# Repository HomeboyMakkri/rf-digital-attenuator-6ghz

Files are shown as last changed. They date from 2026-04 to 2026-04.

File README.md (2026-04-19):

# rf-digital-attenuator-6ghz 📡






A student open-source hardware project featuring a **6-bit Digital RF Attenuator** capable
of operating up to 6 GHz. Controlled by an **STM32F407VET6** and based on the **HMC624A**
(Analog Devices) silicon, this device provides precise signal level control via a simple 
USB-UART CLI or direct SPI interface.
The RF signal path features a grounded coplanar waveguide (GCPW) structure to ensure 50 Ohm impedance matching across the entire operating frequency range.

### Project Context & Disclaimer ⚠️

This project is my first deep dive into the world of embedded systems and RF design. The control logic is implemented using STM32F4 (developed via CubeMX + Keil with HAL libraries), communicating with the HMC624A attenuator via SPI. Serial communication is handled by an FT232RL bridge at a baud rate of 115200.

The hardware was designed from scratch in Altium Designer. Please note: this project is a learning experience. While it is fully functional, it should not be treated as a definitive reference or a textbook example. I am eager to learn and would sincerely appreciate any constructive criticism or suggestions for improvement!

💡 Quick Tip: Check the Project Structure section at the bottom of this file for easy navigation through the firmware and hardware source files.

---
## Control Command to set the attunuation level
Connect via any Serial Terminal (115200 8N1):
* `ATTEN XX.X` — Set attenuation (0 to 31.5)

## 🚀 Features

* **Wide Frequency Range:** Stable performance from 100 MHz to 6.0 GHz.
* **High Precision:** 6-bit attenuation with a fine 0.5 dB step resolution.
* **Robust RF Design:** 50 Ohm matched Coplanar Waveguides (CPW) optimized for 1.6mm FR4.
* **Dual Control:** Command-line interface (CLI) via FT232 USB-UART or high-speed SPI.
* **Plug-and-Play:** Powered and controlled through a single USB Type-C connector.

---

## 📊 Technical Specifications

| Parameter | Value | Notes |
| :--- | :--- | :--- |
| **Frequency Range** | 0.1 — 6.0 GHz | Optimized for 6 GHz |
| **Attenuation Range** | 0 — 31.5 dB | 6-bit control |
| **Step Size** | 0.5 dB | ±0.15 dB Typical Accuracy |
| **Insertion Loss** | ~2.2 dB | @ 2.0 GHz |
| **Input P1dB** | +24 dBm | 1dB Compression Point |
| **Control Interface** | UART (USB) / SPI | 115200 Baud |
| **Input Voltage** | 5.0 V | Via USB Type-C |

---

## 📸 Hardware Gallery

### PCB Overview
| Top View (MCU Side) | Bottom View (RF Side) |
| :---: | :---: |
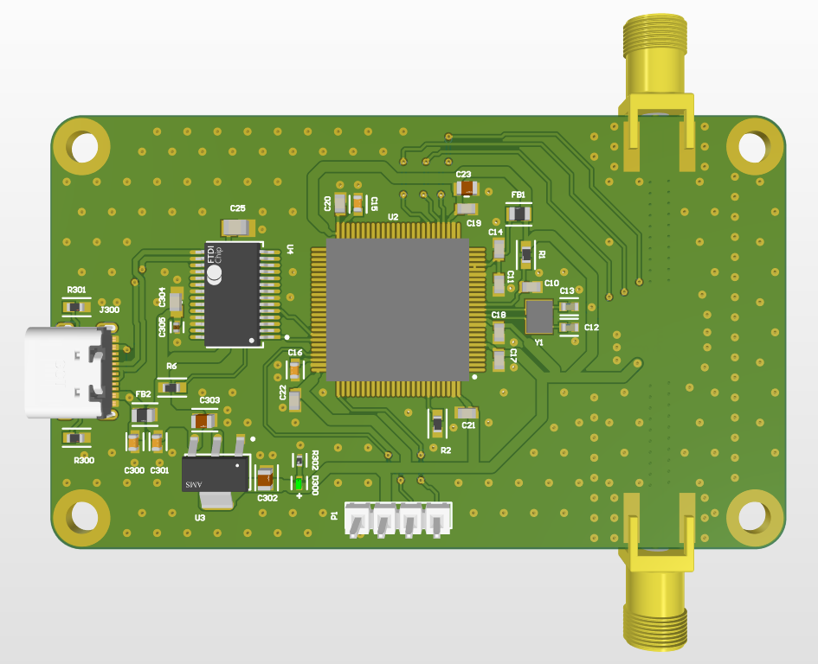
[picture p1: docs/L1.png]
L1
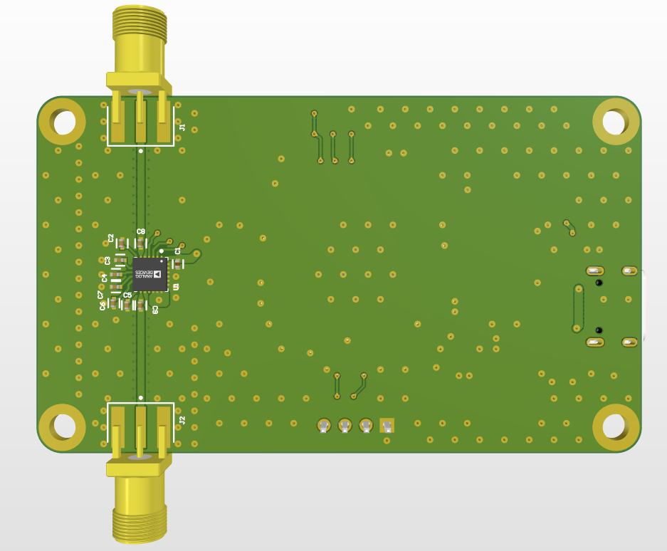
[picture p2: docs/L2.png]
L2
|  |  |

### Key Components
| STM32F407VET6 | HMC624A Attenuator | FT232 UART Bridge |
| :---: | :---: | :---: |
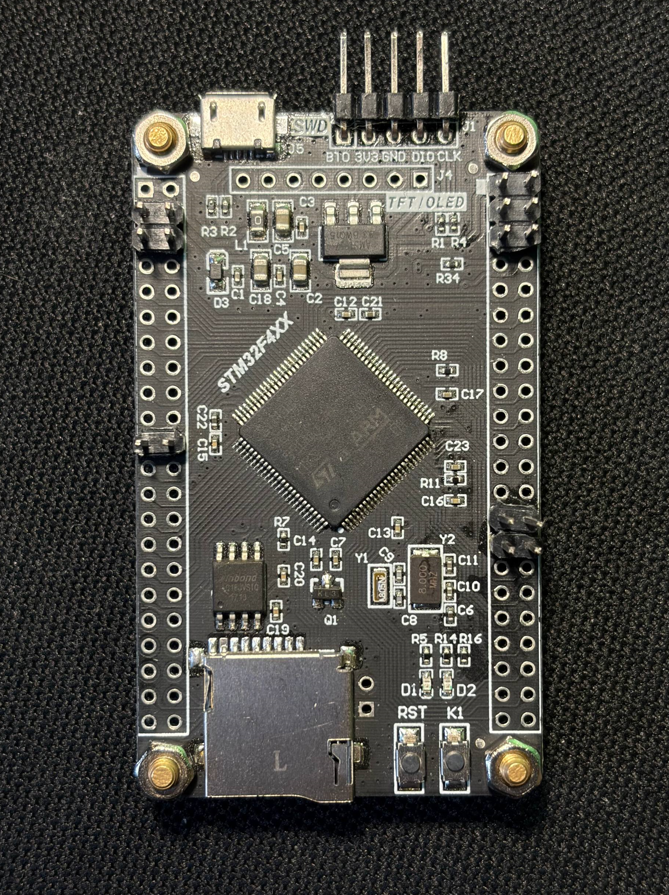
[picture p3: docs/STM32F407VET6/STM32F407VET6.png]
MCU
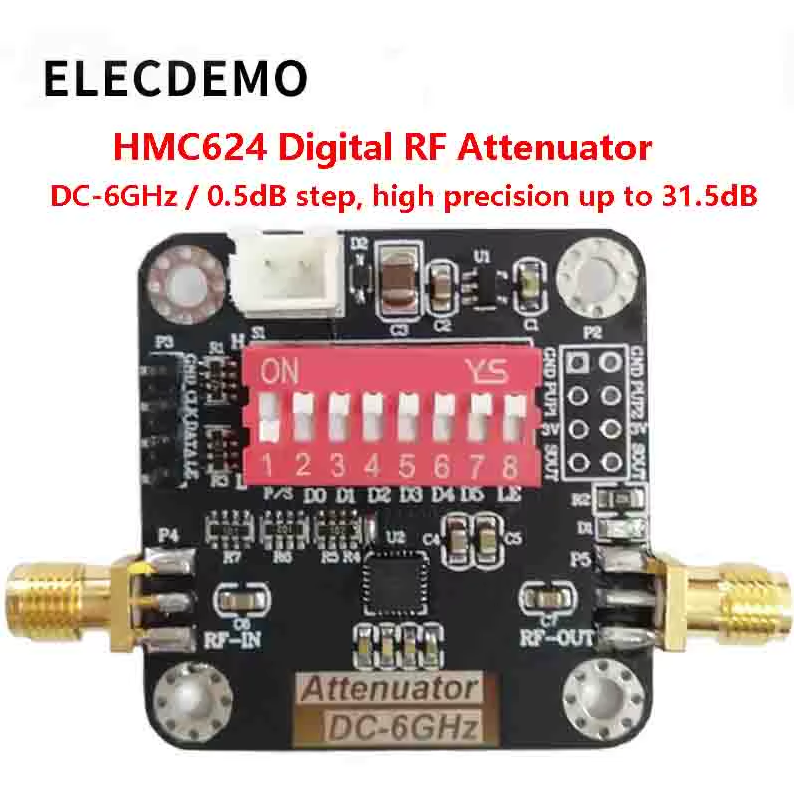
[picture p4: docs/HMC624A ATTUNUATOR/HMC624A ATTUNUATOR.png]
HMC624A
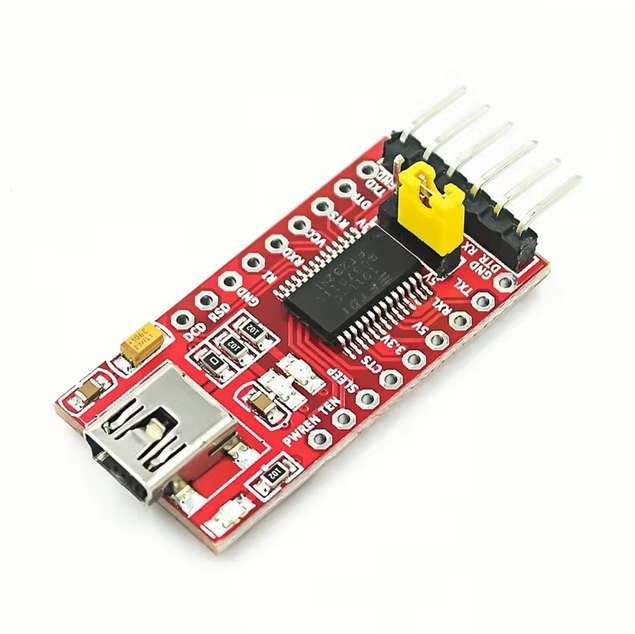
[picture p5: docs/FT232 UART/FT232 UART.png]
FT232
|  |  |  |

---

## 📂 Project Structure

```text
├── hardware/          # Altium Designer project files
│   ├── PDF/           # Schematic exports in PDF format
│   └── Manufacturing/ # Production files (Gerber, BOM, Pick&Place)
├── firmware/          # STM32 Source Code (CubeIDE / Keil)
├── docs/              # Images and reference datasheets
└── README.md          # Project documentation

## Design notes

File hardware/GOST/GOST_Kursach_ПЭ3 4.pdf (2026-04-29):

Изм. Лист | | № докум. | Подп. | Дата
| | Разраб. | Кузнецов М.Д. | | Система управления Перечень элементов | Лит. | Лист | Листов
Пров. | Рогозин А.А. | | | | | | 1 | 4
C1 | Конденсатор 0805 22 мкФ±10% 16В X5R | 1
C2,C3 | Конденсатор 0603 22 мкФ ±20% 16В X5R | 2
| | C4 | Конденсатор 0805 22 мкФ±10% 16В X5R | 1
| | C5 | Конденсатор 0603 0,1 мкФ ±10% 16 В X5R | 1
| | C6 | Конденсатор 0603 10 мкФ +-10% X5R 10В | 1
| | C7 | Конденсатор 0402 0.1 мкФ +-10% X5R 25В | 1
| | C8,C9 | Конденсатор 0603 22 пФ ±5% 16В | 2
| | C10 | Конденсатор 0603 0.10 мкФ +-10% X5R 16В | 1
| | C11 | Конденсатор 0603 0,1 мкФ ±10% 16 В X5R | 1
| | C12,C13 | Конденсатор 0603 2,2 пФ ±0,25 пФ 10В | 2
| | C14,C15 | Конденсатор 0402 330 пФ +-10% X7R 25В | 2
| | C16 | Конденсатор 0402 1.0 нФ +-5% X7R 50В | 1
| | C17 | Конденсатор 0603 0,1 мкФ ±10% 16 В X5R | 1
| | C18,C19 | Конденсатор 0402 330 пФ +-10% X7R 25В | 2
| | C20-C25 | Конденсатор 0603 0,1 мкФ ±10% 16 В X5R | 6
| | C26 | Конденсатор 0805 10 мкФ +-10% X5R 25В | 1
| | C27-C30 | Конденсатор 0402 330 пФ +-10% X7R 25В | 4

Перв. примен.

Поз.
обозначение

Наименование

Кол. | Примечание

Конденсаторы

Справ. №

Н.контр
Утв. | Рогозин А.А.

Инв. № подл.

Подп. и дата

Подп. и дата Взам. инв.№ Инв. № дубл.

# МГТУ.468158.001 ПЭ3

Копировал | Формат А4

Изм. Лист | Подп. | Дата

Микросхемы

DA1 | Микросхема LP5907-3.3 | 1
DD1 | Микросхема STM32F407VET6 | 1
DD2 | Микросхема FT232RL | 1
DD3 | Микросхема HMC624ALP4E | 1

Устройства индикации

H1 | Светодиод CLM1B-RKW | 1

Катушки индуктивности

L1 | Фильтр ферритовый 0805 120 Ом 2 А | 1
| | L2 | Фильтр ферритовый 0805 60 Ом 2 А | 1
Подп. и дата

Резисторы

Инв. № дубл.
R1 | Резистор 0402 (1.2 кОм +-1%) | 1
R2 | Резистор 0603 10 кОм +-5% | 1
R3,R4 | Резистор 0603 5.1 кОм +-5% | 2
R5,R6 | Резистор 0603 10 кОм +-5% | 2
X1 | Розетка USB Type-C USB4105-GF-A | 1
X2 | Вилка штыревая PLD-4 (шаг 2,54 мм) | 1

Соединения контактные

№ докум.

МГТУ.468158.001 ПЭ3 | 2

Подп. и дата Взам. инв.№

Инв. № подл.

Лист

Изм. Лист | Подп. | Дата

Соединители выскочастотные

XW1,XW2 | Розетка приборно-платная SMA | 2

Фильтры, ограничители

Z1 | Резонатор кварцевый KX-38T | 1

Подп. и дата Инв. № дубл.

3

ПЭ3
№ докум.

Подп. и дата Взам. инв.№ Инв. № подл.

Лист

Изм. | Дата
№ докум. | Подп.

Инв. № дубл. Подп. и дата Инв. № подл. Подп. и дата Взам. инв.№

Лист

Изм. | Номера листов (страниц) | Всего листов (страниц) в докум. | № докум. | Входящий № сопроводи-тельного документа и дата | Под-пись | Дата
изменен-ных | заменен-ных | новых | аннули-рован-ных

ПЭ3

Лист
4

Лист регистрации изменений

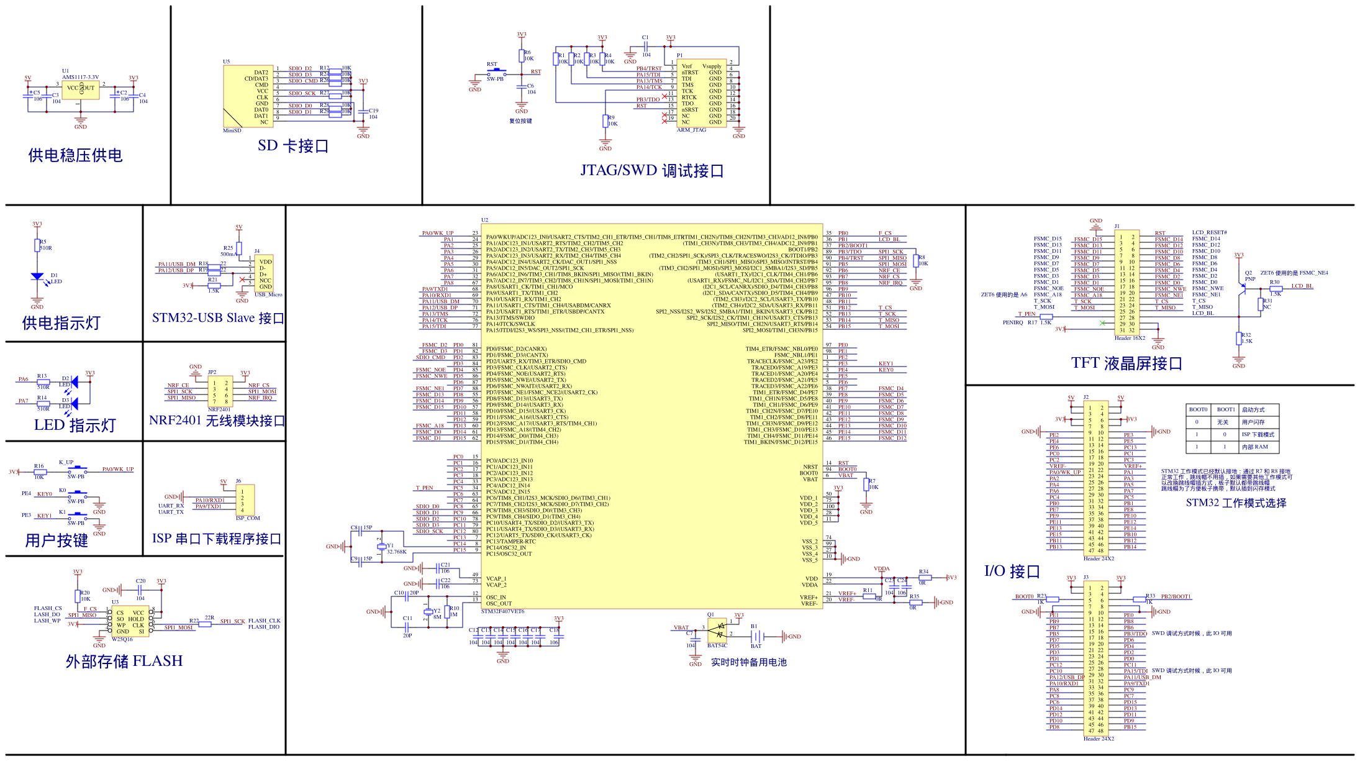
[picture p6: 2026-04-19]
docs/STM32F407VET6/839350471715408aa0b24b855806e64d.png

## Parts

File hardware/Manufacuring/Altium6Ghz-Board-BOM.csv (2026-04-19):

Comment | Description | Designator | Footprint | LibRef | Quantity
1n | Cap Ceramic 0.001uF 50V X7R 10% Pad SMD 0402 125C Automotive T/R | C1 | FP-C0402-BB-MFG | CMP-2008-02329-2 | 1
300p | CC0402 330 pF X7R 10.00% 25 V | C2, C3, C4, C5, C6, C7, C8, C9 | FP-CC0402-MFG | CMP-03422-000106-1 | 8
0.1u |  | C10, C11, C14, C17, C18, C19, C20, C21, C22 | CAPC1608X92X38NL15T08 | CMP-2006-01166-1 | 9
22p | C0603 22 pF X7R 30ppm/°C 10.00% 100 V | C12, C13 | FP-C0603C-CF-MFG | CMP-03020-026609-1 | 2
2.2p | CC0603 2.2 uF X7R 10.00% 10 V | C15, C16 | FP-CC0603-DA-MFG | CMP-03422-000630-1 | 2
10u | Chip Multilayer Ceramic Capacitors for General Purpose, 0805, 10uF, X5R, 15%, 20%, 50V | C23 | FP-GRM21B-0_2-e0_2_0_7-MFG | CMP-06035-044754-1 | 1
100nF |  | C25 | CAPC2013X145X50ML20T25 | CMP-1036-04420-2 | 1
2u2 | CAP CER 2.2UF 16V X5R 0603 | C300, C301 | FP-CC0603-DA-MFG | CMP-03422-000257-1 | 2
22u | Chip Multilayer Ceramic Capacitors for General Purpose, 0805, 22uF, X5R, 15%, 20%, 16V | C302, C303 | FP-GRM21B-0_2-e0_2_0_7-IPC_C | CMP-06035-025383-1 | 2
10uF | CAP 10uF 6.3V ±10% 0603 (1608 Metric) Thickness 1mm SMD | C304 | CAPC0603(1608)100_M | CMP-1035-02796-1 | 1
100 nF | CAP CER 0.1UF 25V X5R 0402 | C305 | FP-C0402-BB-MFG | CMP-03020-014070-2 | 1
led | LED GREEN CLEAR 0402 SMD | D300 | FP-SM0402GC-MFG | CMP-35283-000001-2 | 1
BLM21PG600BH1D | Chip Ferrite Bead, 0805, 60? @ 100MHz, 0.02?, 25%, 1.9A | FB1 | FP-BLM21-0_2-t0_85-e0_5-IPC_C | CMP-06046-002606-1 | 1
120R | Chip Ferrite Bead, 0805, 60? @ 100MHz, 0.02?, 25%, 1.9A | FB2 | FP-BLM21-0_2-t0_85-e0_5-IPC_C | CMP-06046-002606-1 | 1
CON-SMA-EDGE-S | CONN SMA JACK STR EDGE MNT | J1, J2 | FP-CON-SMA-EDGE-S-MFG | CMP-204357-000001-1 | 2
USB4105-GF-A-060 | USB Connector Type C SMT 12 Pin | J300 | USB4105-GF-A-060 | USB4105-GF-A-060 | 1
Programmator | 0.025" SQ Post Header, Through-hole, Vertical, -55 to 125 degC, 2.54 mm Pitch, 4-Pin, Male, RoHS | P1 | SMTC-TSW-104-08-X-S | CMP-1024-00357-1 | 1
10k | RES 10k? 5.00% 0.2W 0603 | R1, R2, R6 | FP-AC0603-IPC_A | CMP-03412-040683-1 | 3
5k | RES Thin Film, 4k?, 0.1%, 0.1W, 25ppm/°C, 0603 | R300, R301 | FP-TFCR0603-IPC_A | CMP-250906-062905-1 | 2
1k | RES SMD 1.2K OHM 1% 1/10W 0402 | R302 | FP-MCS0402-IPC_C | CMP-2002-02445-2 | 1
HMC624ALP4ETR | RF ATTENUATOR 31.5DB 50OHM 24QFN | U1 | FP-CP-24-16-IPC_C | CMP-09141-000007-1 | 1
STM32F407VET6 | ARM Cortex-M4 32-bit MCU+FPU, 210 DMIPS, 512 kB Flash, 192 kB Internal RAM, 82 I/Os, 100-pin LQFP, -40 to 85 degC, Tray | U2 | STM-LQFP100_M | CMP-0243-00016-3 | 1
LDO | LDO Voltage Regulators 1A, 3.3V | U3 | FP-AMS1117-IPC_C | CMP-209535-000001-1 | 1
FT232RL-REEL | IC USB FS SERIAL UART 28-SSOP | U4 | FP-SSOP-28-MFG | CMP-0078-00029-4 | 1
NX3225GD-8MHZ-STD-CRA-3 | Crystal Unit, 8 MHz, 8 pF, -40 to 150 degC, 2-Pin SMD, RoHS, Tape and Reel | Y1 | NDK-NX3225GD-8MHZ-STD-CRA-3_V | CMP-2000-07595-1 | 1

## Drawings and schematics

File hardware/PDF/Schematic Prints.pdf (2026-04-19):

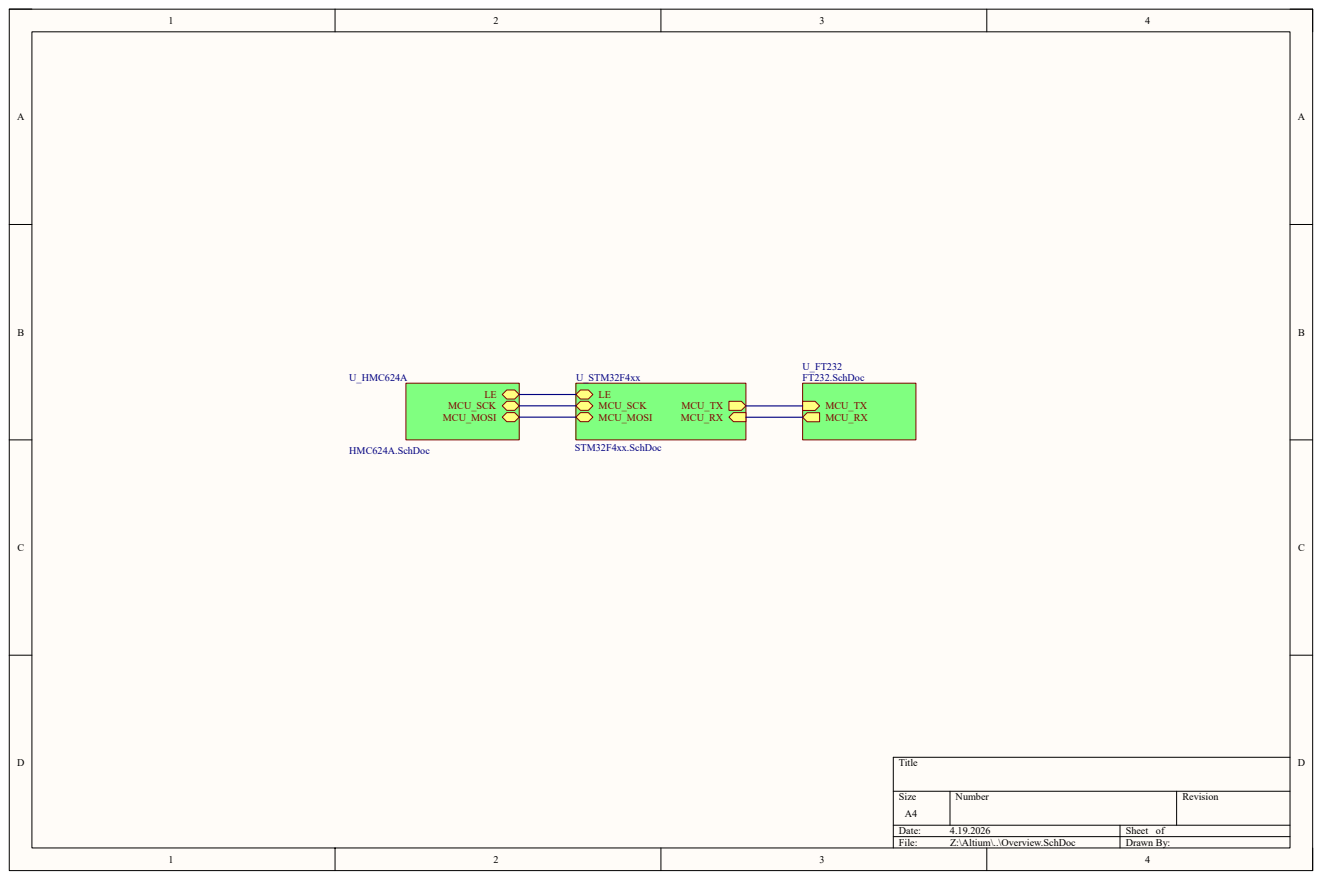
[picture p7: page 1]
Title; LE MCU_SCK MCU_MOSI; U_HMC624A; HMC624A.SchDoc; MCU_TX; MCU_MOSI; MCU_RX; MCU_SCK; U_STM32F4xx; STM32F4xx.SchDoc; MCU_TX MCU_RX; U_FT232 FT232.SchDoc

Size A4 | Number | Revision

Date: 4.19.2026 | Sheet of
File: Z:\Altium\..\Overview.SchDoc | Drawn By:

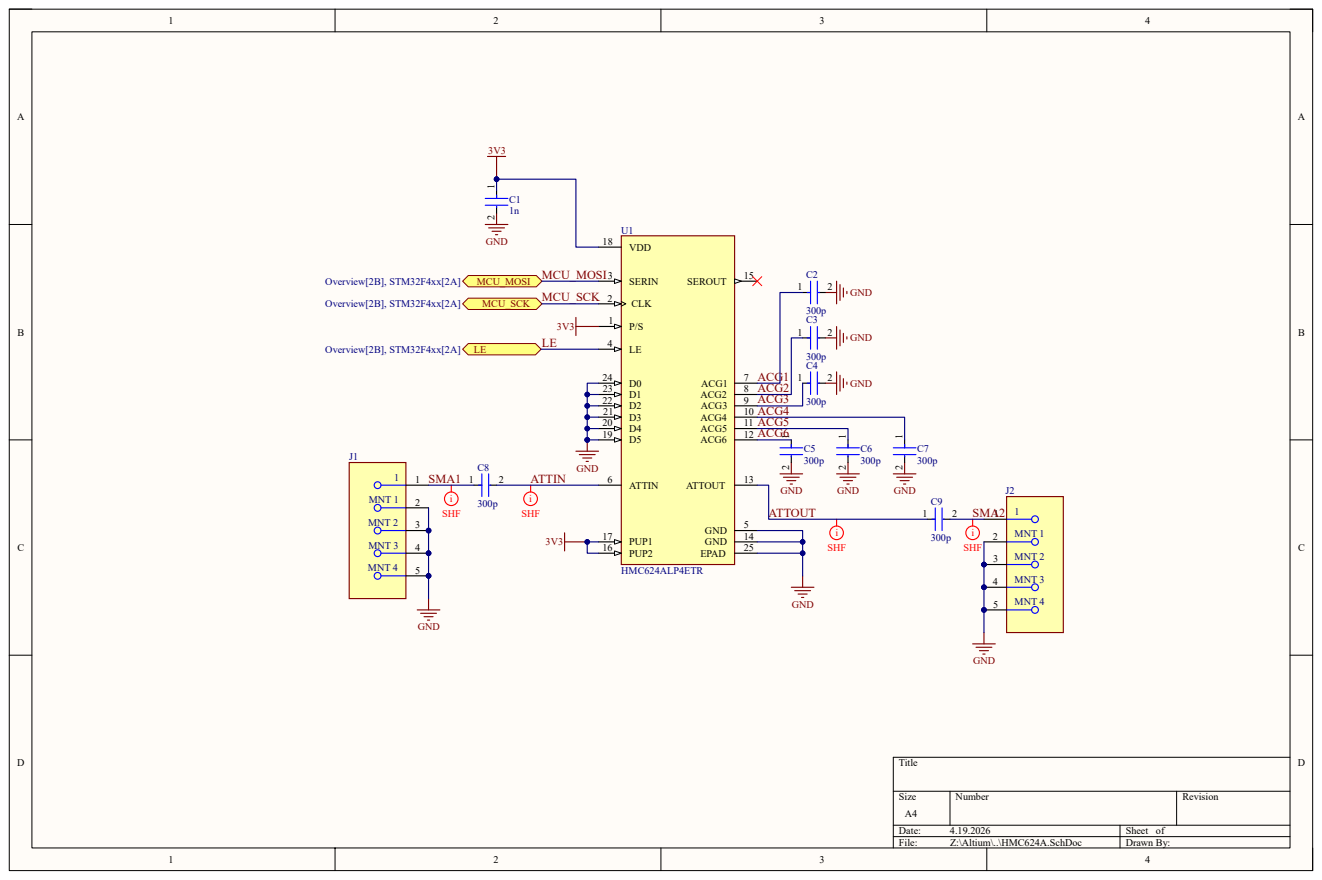
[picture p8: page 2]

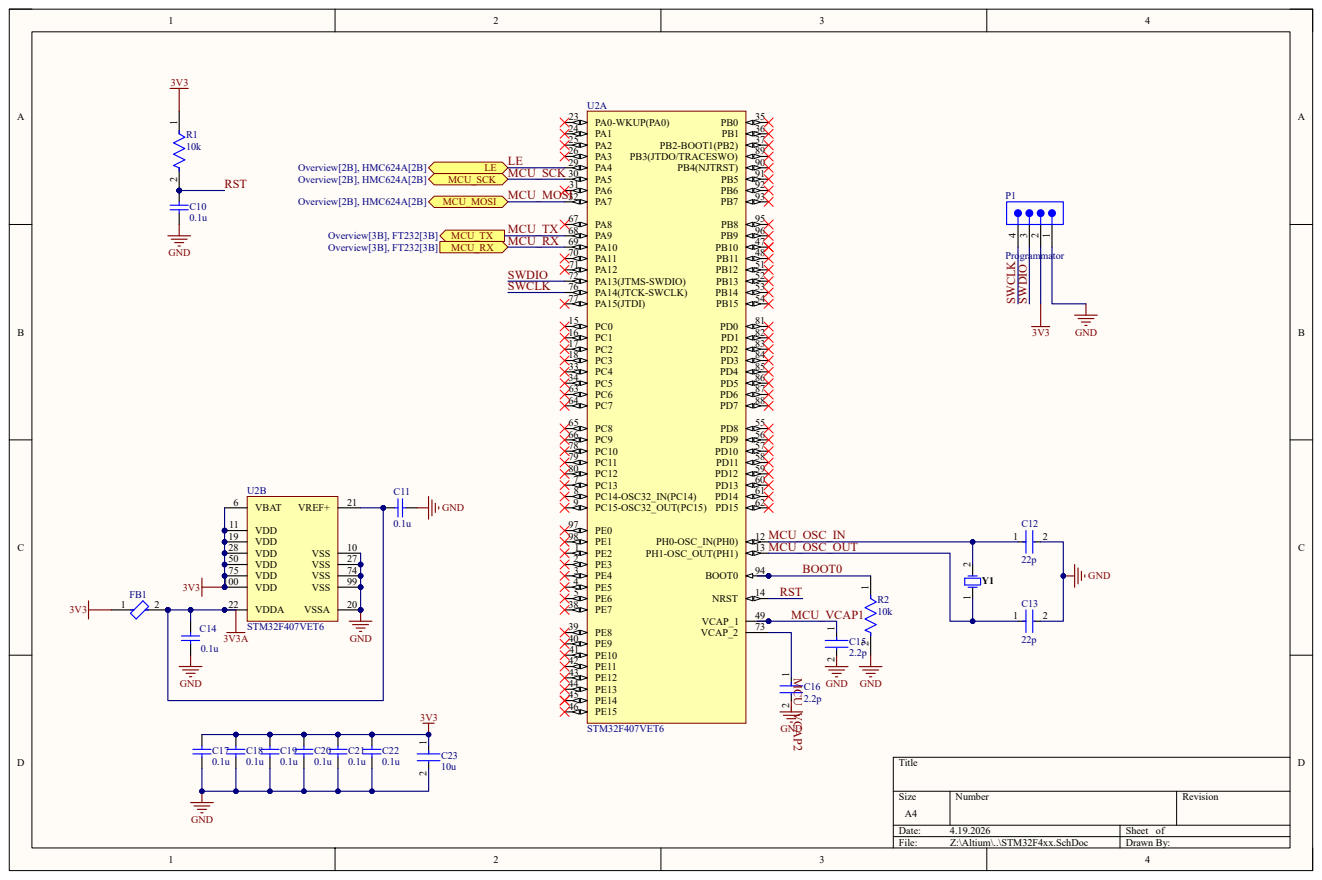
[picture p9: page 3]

## USB C

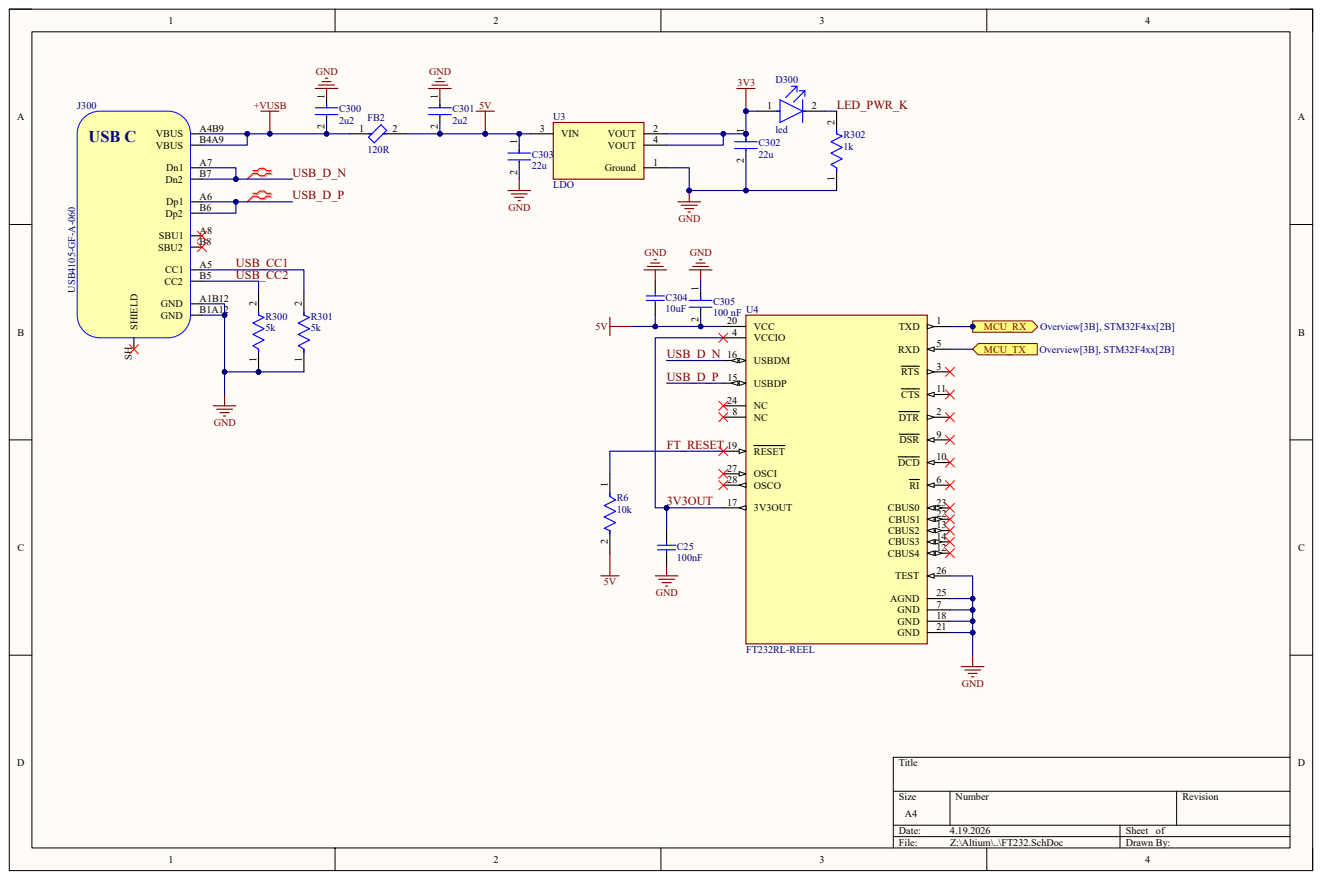
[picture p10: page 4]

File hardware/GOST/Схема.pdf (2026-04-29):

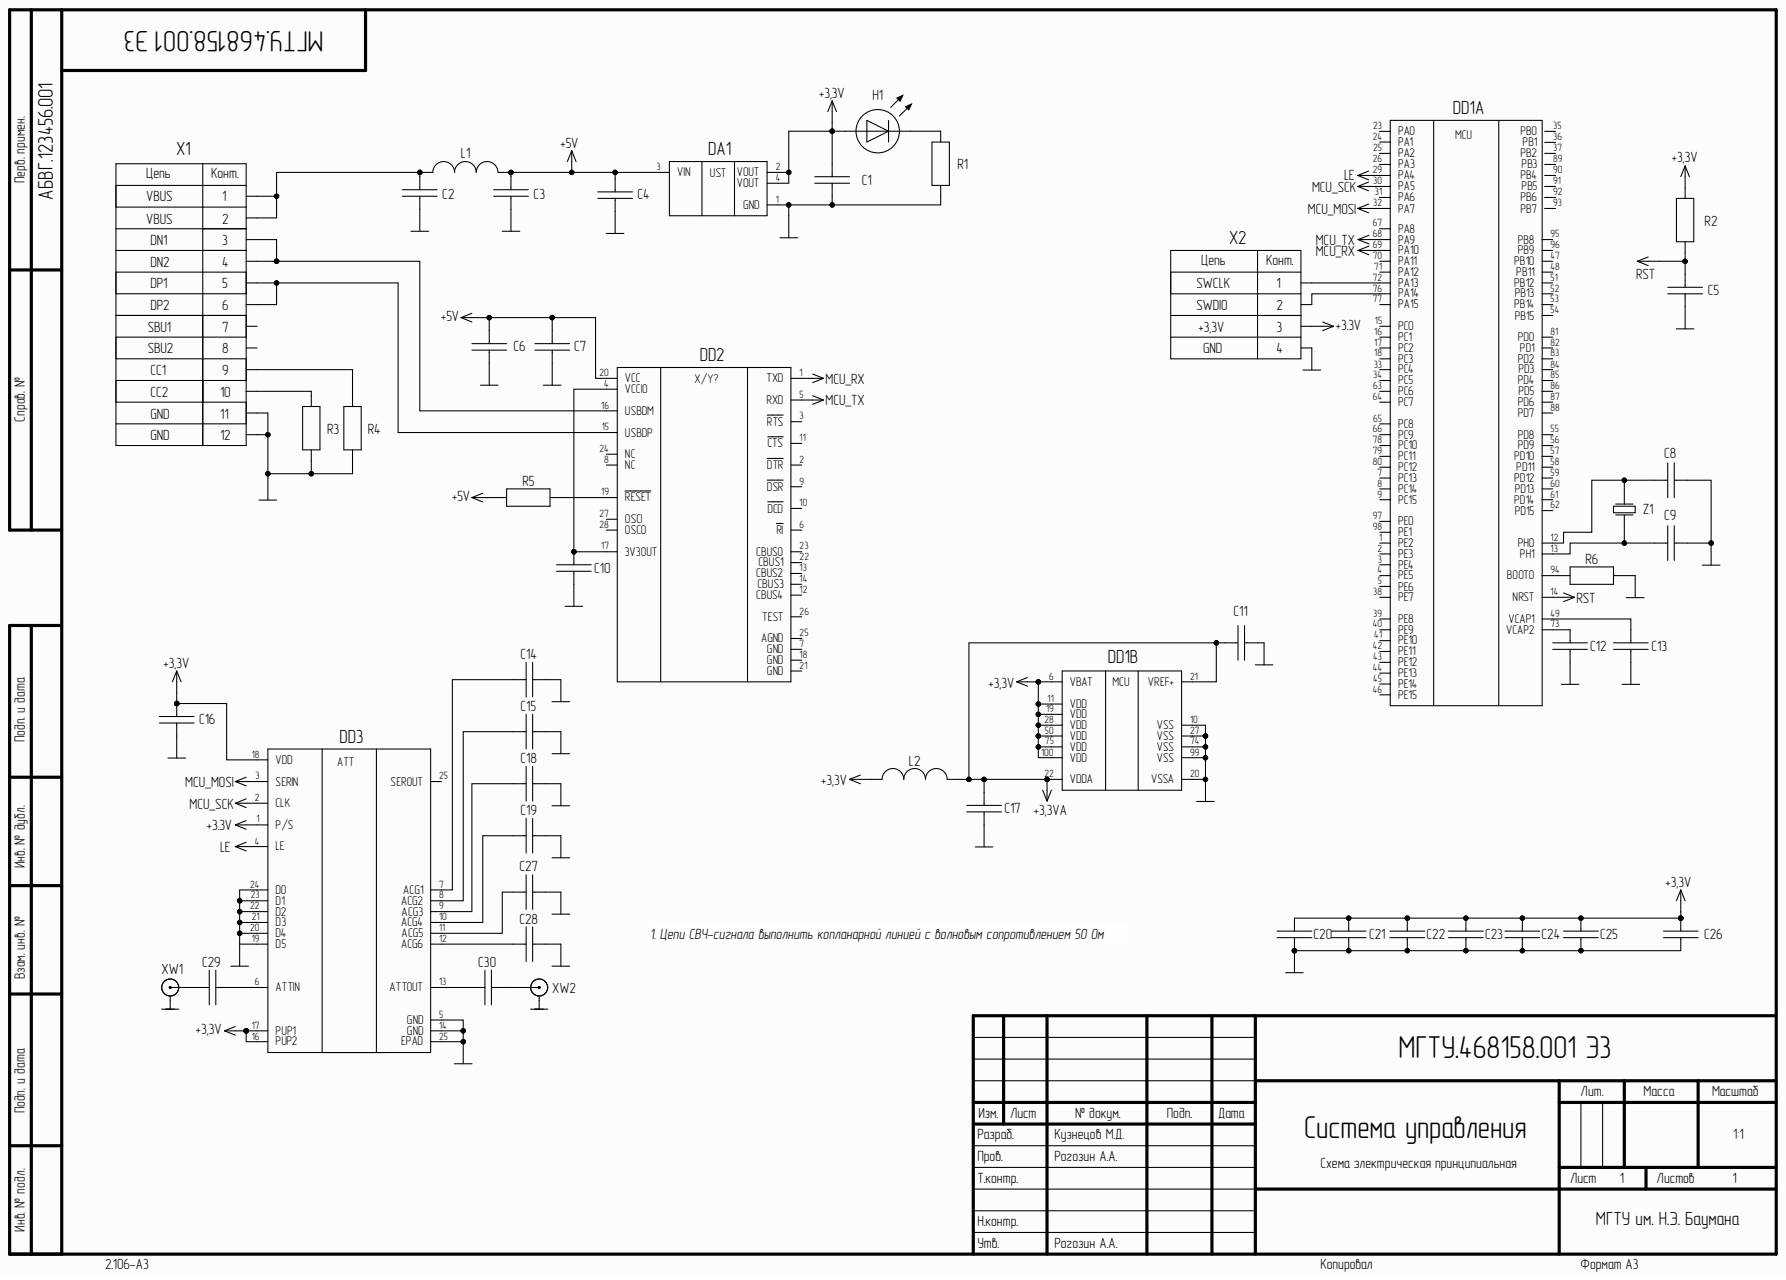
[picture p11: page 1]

Инв. № подл. Инв. № дубл. Подп. и дата Взам. инв. № Подп. и дата Перв. примен. Справ. №

Цепи СВЧ-сигнала выполнить копланарной линией

Система управления Схем а электрическая принципиальная | Лит . | Масса | Масшта б

Изм . | Лис т | № докум . | Подп . | Дат а | | | | | 1:1
Разраб . | | Кузнецов М . Д .
Пров . | | Рогозин А . А .
Т .контр . | | | | | Лис т 1 | Листо в 1

Н .контр .
Утв . | Рогозин А . А .

МГТУ им . Н . Э . Баумана

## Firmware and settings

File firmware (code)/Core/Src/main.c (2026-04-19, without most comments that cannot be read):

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
/* Includes ------------------------------------------------------------------*/
#include "main.h"

/* USER CODE BEGIN Includes */
#include <string.h>
#include <stdio.h>
#include <stdlib.h>
#include <math.h>

/* USER CODE END Includes */

SPI_HandleTypeDef hspi1;

UART_HandleTypeDef huart1;

/* USER CODE BEGIN PV */
uint8_t rxBuffer[32];
uint8_t txBuffer[64];
volatile uint8_t rxComplete = 0;


char debugMsg[64];
/* USER CODE END PV */

void SystemClock_Config(void);
static void MX_GPIO_Init(void);
static void MX_SPI1_Init(void);
static void MX_USART1_UART_Init(void);
/* USER CODE BEGIN 0 */
void SetAttenuation(float dB)
{

    if (dB < 0)   dB = 0;
    if (dB > 31.5) dB = 31.5;


    uint8_t code = (uint8_t)round(dB / 0.5f);


    // D5..D0 = code (MSB first)

    HAL_GPIO_WritePin(GPIOA, GPIO_PIN_4, GPIO_PIN_RESET);   // LE = 0


    uint8_t data = code & 0x3F;
    HAL_SPI_Transmit(&hspi1, &data, 1, 100);


    HAL_GPIO_WritePin(GPIOA, GPIO_PIN_4, GPIO_PIN_SET);
    HAL_Delay(1);
    HAL_GPIO_WritePin(GPIOA, GPIO_PIN_4, GPIO_PIN_RESET);


    sprintf((char*)txBuffer, "OK: %.1f dB set (code %d)\r\n", dB, code);
    HAL_UART_Transmit(&huart1, txBuffer, strlen((char*)txBuffer), 200);
}
/* USER CODE END 0 */

/**
  * @brief  The application entry point.
  * @retval int
  */
int main(void)
{

  /* MCU Configuration--------------------------------------------------------*/

  /* Reset of all peripherals, Initializes the Flash interface and the Systick. */
  HAL_Init();

  /* Configure the system clock */
  SystemClock_Config();

  /* Initialize all configured peripherals */
  MX_GPIO_Init();
  MX_SPI1_Init();
  MX_USART1_UART_Init();
  /* USER CODE BEGIN 2 */
	HAL_UART_Receive_IT(&huart1, rxBuffer, 1);
  /* USER CODE END 2 */

  /* Infinite loop */
  /* USER CODE BEGIN WHILE */
	while (1)
	{
		//HAL_UART_Transmit(&huart1, (uint8_t*)"Test from STM32\r\n", 17, 100);
		//HAL_Delay(1000);
			if (rxComplete)
			{
					rxComplete = 0;



					char *cmd = strstr((char*)rxBuffer, "ATTEN");
					if (cmd)
					{
							float dbValue = 0.0f;

							if (sscanf(cmd + 5, "%f", &dbValue) == 1)
							{
									SetAttenuation(dbValue);
							}
							else
							{
									sprintf((char*)txBuffer, "ERROR: invalid format\r\n");
									HAL_UART_Transmit(&huart1, txBuffer, strlen((char*)txBuffer), 200);
							}
					}
					else
					{
							sprintf((char*)txBuffer, "ERROR: unknown command\r\n");
							HAL_UART_Transmit(&huart1, txBuffer, strlen((char*)txBuffer), 200);
					}
					memset(rxBuffer, 0, sizeof(rxBuffer));
			}

			HAL_Delay(10);
			
	}
    /* USER CODE END WHILE */

    /* USER CODE BEGIN 3 */
  }
  /* USER CODE END 3 */


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
/* USER CODE BEGIN 4 */
void HAL_UART_RxCpltCallback(UART_HandleTypeDef *huart)
{
    static uint8_t rxIndex = 0;

    if (huart->Instance == USART1)
    {
        if (rxBuffer[rxIndex] == '\n' || rxBuffer[rxIndex] == '\r' || rxIndex >= 31)
        {
            rxBuffer[rxIndex] = '\0';
            rxComplete = 1;
            rxIndex = 0;
        }
        else
        {
            rxIndex++;
        }


        HAL_UART_Receive_IT(&huart1, &rxBuffer[rxIndex], 1);
    }
}
/* USER CODE END 4 */
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


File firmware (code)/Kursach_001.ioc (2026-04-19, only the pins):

Mcu.UserName=STM32F407VETx
PA10.Signal=USART1_RX
PA13.Signal=SYS_JTMS-SWDIO
PA14.Signal=SYS_JTCK-SWCLK
PA4.GPIO_Label=LE_Pin
PA4.Signal=GPIO_Output
PA5.Signal=SPI1_SCK
PA6.Signal=SPI1_MISO
PA7.Signal=SPI1_MOSI
PA9.Signal=USART1_TX
PH0-OSC_IN.Signal=RCC_OSC_IN
PH1-OSC_OUT.Signal=RCC_OSC_OUT

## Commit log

2026-04-19 init commit
    [Altium6Ghz-Board-BOM.csv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]
2026-04-19 Fix: converted submodule to regular folder
    [FT232.SchDoc, HMC624A.SchDoc, Kursach001.PrjPcb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]
2026-04-29 GOST_scheme added, Quick PCB fix
    [FT232.SchDoc, GOST_Kursach.PrjPcb, HMC624A.SchDoc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]
2026-05-01 schematic GOST

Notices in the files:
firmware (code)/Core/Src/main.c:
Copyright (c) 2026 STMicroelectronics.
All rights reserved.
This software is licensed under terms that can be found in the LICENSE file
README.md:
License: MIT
